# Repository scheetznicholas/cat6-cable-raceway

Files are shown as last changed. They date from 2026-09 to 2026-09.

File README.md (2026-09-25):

# Cat6 Cable Raceway (5-cable bundle, snap-on cover)

Printable wall raceway for a bundle of five Cat6 cables: straights, a flat 90° elbow, inside/outside
room-corner pieces and end caps.  Bambu H2S project files included.

| | |
|---|---|
| outer size | 32 wide × 20 tall |
| interior | 25.9 × 17.6 mm — 5 Cat6 stacked 3+2 with room, even 7 mm thick-jacket cable |
| cover | one-piece snap-over, 1.2 mm top and legs, 0.8 mm chamfered edges |
| base | 1.2 mm floor with lightening windows and 2 mm screw pads, 10 mm walls, countersunk #6 / M3.5 screw holes every 100 mm (or foam tape on the rails) |
| snap | 0.75 mm ridges on both parts with 20° hooked retention faces and 0.1 mm lateral preload: the sprung legs pull the cover tight to the wall, no rattle. 0.85 mm engagement, 0.70 % leg strain during snap-on, 0.20 % resting |
| filament | rev 2 (2026-09-24) uses ~36 % less than rev 1: 232 cm³ / ~290 g PLA per project, 38 cm³ per 300 mm of run |

## Files

- `CableRaceway_H2S_PLA.3mf` — Bambu PLA Basic, 0.20 mm, 3 walls, 15 % gyroid (all sections are solid walls anyway), no supports (2 plates)
- `CableRaceway_H2S_PETG.3mf` — same layout in Bambu PETG HF (tougher snap legs if the cover will come off a lot)
- `stl/` — every part, already in print orientation
- `generate_raceway.py` — build123d generator (all dimensions are parameters at the top)
- `check_mechanism.py` — solid-boolean fit checks: cover seats on the relaxed geometry without interference, the
  hooks retain it when lifted, the snap starts freely, the real geometry interferes only by the designed preload
  sliver at the ridges, a 21 × 14 mm cable bundle clears every piece, screw heads seat, end cap fits, leg strain,
  overhang audit of every STL (`check_mechanism.log` = last run, ALL PASS)
- `make_3mf.py` — builds the 3MF via the Bambu Studio CLI (`--petg` for the PETG version)

## What's in one project (per print of both plates)

| part | qty | what it is |
|---|---|---|
| straight_base_300 / straight_cover_300 | 4 + 4 | 1.2 m of run |
| straight_base_150 | 1 | half base so cover joints never sit over base joints |
| elbow_flat_base / elbow_flat_cover | 2 + 2 | 90° bend within the same wall (baseboard run turning up to a jack) |
| corner_inside_cover + corner_inside_base_stub | 1 + 2 | run goes around an inside (concave) room corner |
| corner_outside_cover + corner_outside_base_stub | 1 + 2 | run goes around an outside (convex) corner |
| end_cap | 2 | plugs an open end |

Need more run: duplicate plate 1 in Bambu Studio (or `Ctrl+D` the straights).  Don't need a corner type: delete it.

## Install

1. Start the base run with the 150 mm piece, then 300s.  Screw through the floor holes (#6 wood screws or
   drywall anchors) or use foam tape on the floor.  Butt base pieces end to end; the joints are hidden.
2. Flat elbow: the base is an L with a screw hole in each arm; the straight bases butt against its 55 mm arms
   and its 70 mm cover overlaps the joint.
3. Room corner: screw one stub to each wall with their mitred ends meeting at the corner, then the one-piece
   corner cover presses straight into the corner (both arms snap at once).  Straight base/cover continue from
   the stub ends.
4. Lay the cables in, then press each cover on: it has a lead-in ramp and clicks when seated.  The legs are
   sprung against the base and the ridges are hooked, so the cover is pulled tight to the wall and won't rattle
   or pop off.  To remove, slip a putty knife under a leg at the wall and lever the leg outward (about 1 mm)
   while lifting; work along the piece.
5. End caps push into the open interior at the run ends.

Cover joints on a long run: cut a straight cover shorter with a hacksaw if a joint would land on an elbow arm.

## Print notes

- Everything prints support-free in the exported orientation: bases floor-down, covers top-down, corner
  covers with one arm flat and the other standing.  The inside-corner cover stands on its leg edges, so it has
  a 5 mm per-object brim; the run under its flat arm is a 29.6 mm bridge (fine on an H2S).  The hooked retention
  faces are 0.8 mm ledges tilted 20°, the same two-line cantilever the rev 1 flat ledges were.
- Regenerate after changing parameters: `generate_raceway.py` → `check_mechanism.py` (must print ALL PASS) →
  `make_3mf.py`.
- If a printed cover feels too tight/loose, change `PRELOAD` (0.10; raise for tighter) or `VERT` (-0.05) in the
  generator and reprint one 150 mm base + cover to test; the other pieces inherit the same profile.  Rev 1
  (flat faces, 0.15/0.2 mm clearances, 1.6 mm sheets) printed fine but felt loose — that is why rev 2 preloads.
- Filament: set `FLOOR_WINDOWS = False` for a solid base floor (e.g. if you want full-width tape contact);
  it costs about 3.5 cm³ per 300 mm base.  Sheets are 1.2 mm = three 0.4 mm walls, so 2–3 wall loops print them solid.

## Wall-entry kit (run terminates into a stud bay)

Instead of ending a run with an `end_cap`, the run can dump its cables straight through the drywall into the
bay behind.  The plate *is* a piece of raceway: its front face carries the same outer profile and the same
absolute snap-ridge heights as a straight base, so stock covers and elbows mate to it flush.  Its floor is
2.4 mm instead of 1.2 (that floor is the visible face plate), and the floor simply stops over a
**25 × 44 mm hole** that drops into the wall.

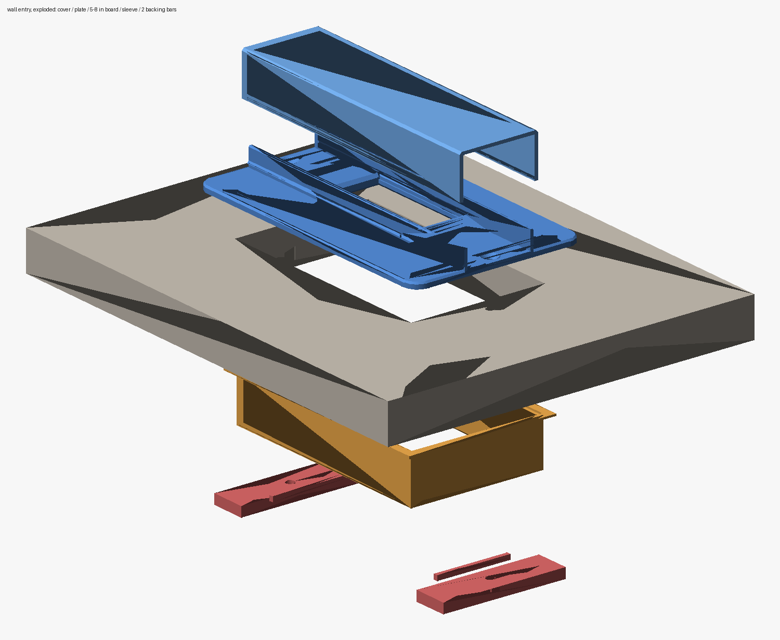
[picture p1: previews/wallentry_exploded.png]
exploded

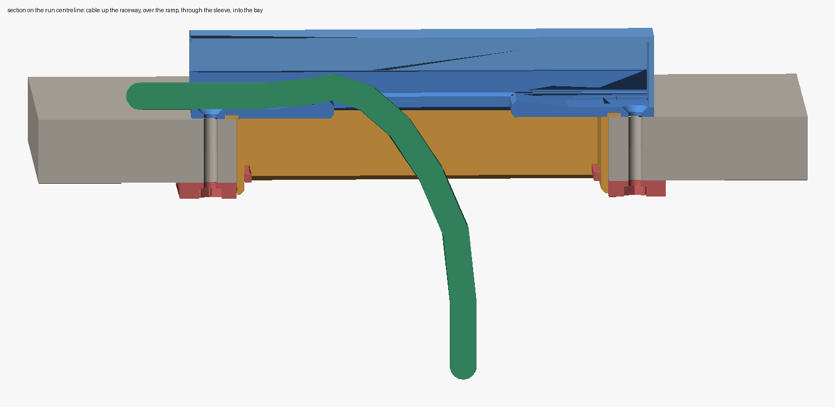
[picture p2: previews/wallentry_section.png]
section


| | |
|---|---|
| face plate | 69.85 × 114.3 mm — standard US single gang, 6 mm corner radius, 0.6 mm chamfer |
| wall cutout | 54.8 × 92.1 mm — Arlington LV1 low-voltage bracket size, so an off-the-shelf bracket or brush plate fits the same hole later |
| cable hole | 25 × 44 mm with 14 mm ramps each side (2 mm crest, 14.4 mm still clear under the cover).  44 mm is set by Cat6's 25 mm static bend radius (4 × OD) |
| sleeve | 60.2 × 97.5 mm lip, 19 mm deep — lines the cut so no cable ever touches cut gypsum.  The lip is **9.6 mm narrower and 16.8 mm shorter than the face plate** (4.83 mm hidden each side, 8.4 top and bottom) and nests in a 0.95 mm groove in the plate's back, so the plate still beds flat on the wall |
| fixing | two printed backing bars, no studs and no drywall anchors: each passes through the cutout, turns behind the board and clamps 691 mm² of intact gypsum (1382 mm² for the pair) |
| board | verified on both 1/2 in (12.7 mm) and 5/8 in (15.9 mm) |
| hardware | 2 × M3 × 30 countersunk + 2 × M3 nuts (nuts are captive in the bars).  On 5/8 in board the screw reaches 24.7 mm, leaving 5.3 mm spare |

### Files

- `WallEntry_H2S_PLA.3mf` / `WallEntry_H2S_PETG.3mf` — one plate, 6 objects: plate, cover, sleeve, 2 bars, template
- `generate_wallplate.py` — generator; imports `generate_raceway` and reuses its profile so the two can't drift
- `check_wallplate.py` — solid-boolean fit checks (`check_wallplate.log` = last run, ALL PASS)
- `render_wallentry.py` — the exploded and section previews above
- `make_3mf.py --wall` (add `--side` for a side-entry run, `--petg` for PETG) — builds the wall 3MF

### Parts

| part | qty | what it is |
|---|---|---|
| wallplate_entry_bottom | 1 | plate for a run arriving from below/above (along the plate's long axis) |
| wallplate_entry_side | - | same plate for a run arriving from the left/right — build with `--side` instead |
| wallplate_cover_bottom / _side | 1 | short cover with a **closed end**, trimmed to sit on the 2.4 mm floor |
| wall_sleeve | 1 | lines the cutout |
| wall_backing_bar | 2 | the clamp |
| wall_cut_template | 1 | 109.9 × 154.3 × 1.6 mm; trace the cutout and mark both screw holes |

The kit `end_cap` does **not** fit the plate — the plate's floor is 2.4 mm, so the cap would sit 1.2 mm proud
and its legs would foul.  Use `wallplate_cover_*`, whose far end is closed, as the end of the run.

### Install

1. Hold `wall_cut_template` on the wall where the run ends, level it, trace the 54.8 × 92.1 mm window and mark
   the two screw holes 52.5 mm above and below centre.  Check the bay is clear before cutting.
2. Cut the window (drywall saw) and drill the two 3.4 mm screw holes.
3. Thread an M3 × 30 countersunk screw through each plate hole and into the nut captive in a backing bar, a
   few turns only.  Feed each bar diagonally through the cutout, turn it flat behind the board and pull it
   back against the gypsum — the single rib on the bore side keys it against rotation, and the screw carries it.
4. Push the sleeve into the cutout from the front, lip against the wall face.
5. Set the plate over the sleeve (its back groove swallows the lip), then tighten both screws evenly until the
   bars bite.  Don't overtighten — you're clamping gypsum.
6. Bring the run in: the last base piece butts to the plate, cables lie over the ramps and drop through the
   hole into the bay.
7. Clip the closed-end cover on last; the hole and the screws disappear under it.

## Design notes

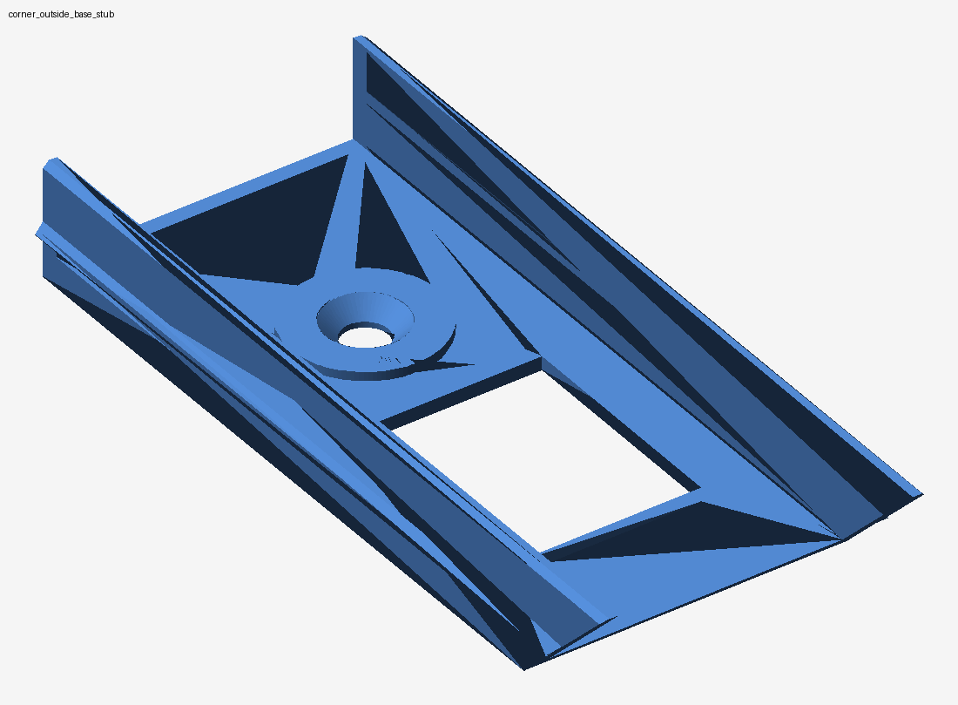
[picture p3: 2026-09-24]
previews/corner_outside_base_stub_iso.png

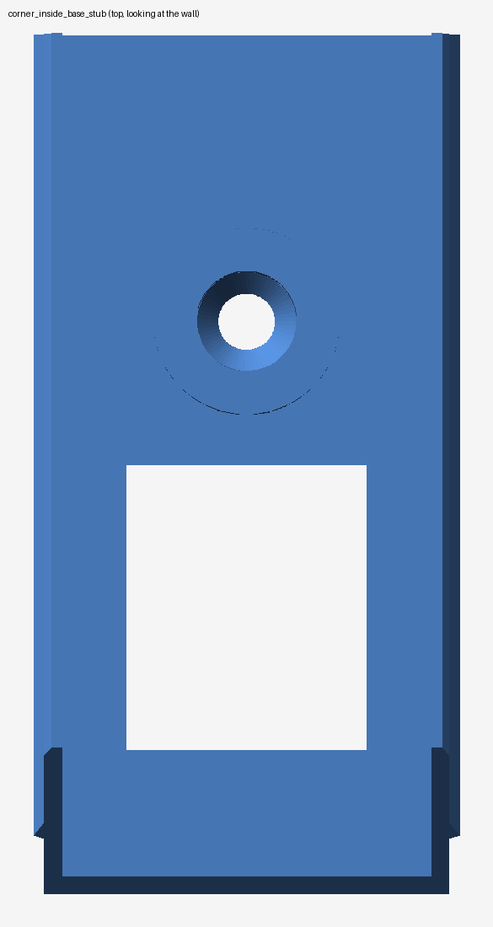
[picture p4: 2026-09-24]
previews/corner_inside_base_stub_top.png

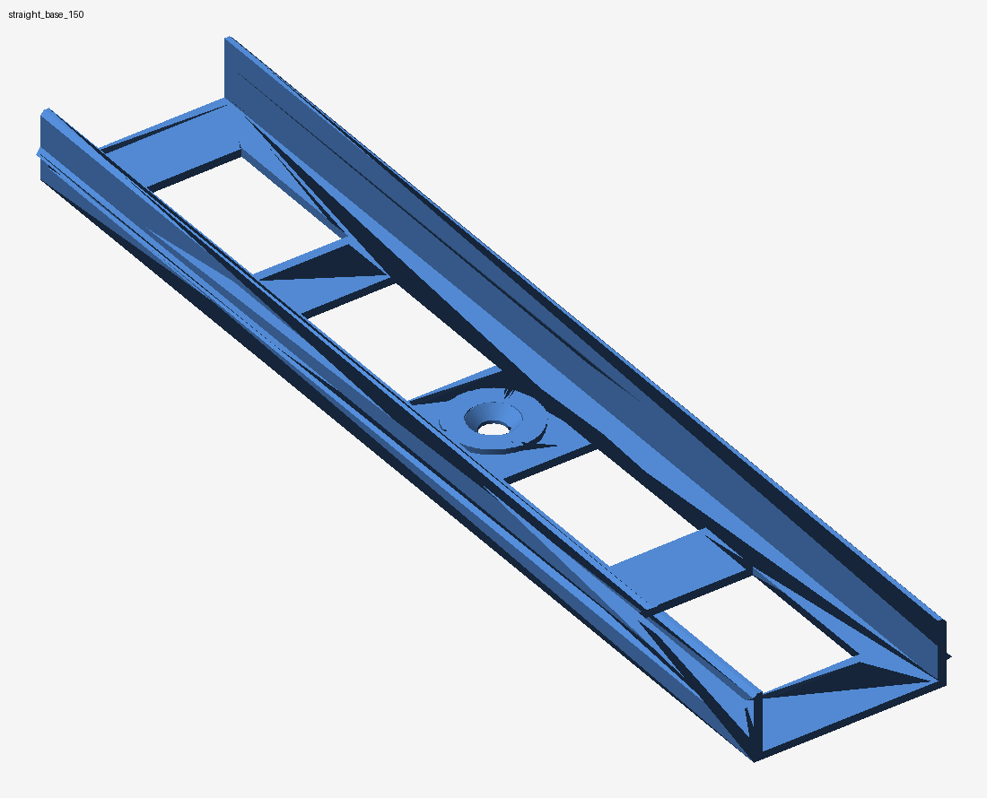
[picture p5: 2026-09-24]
previews/straight_base_150_iso.png

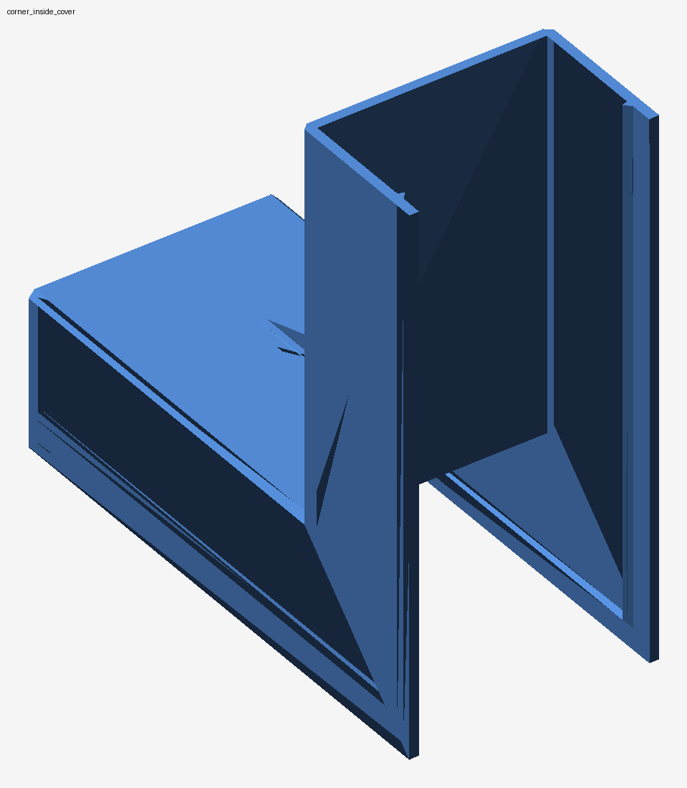
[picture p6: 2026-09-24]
previews/corner_inside_cover_iso.png

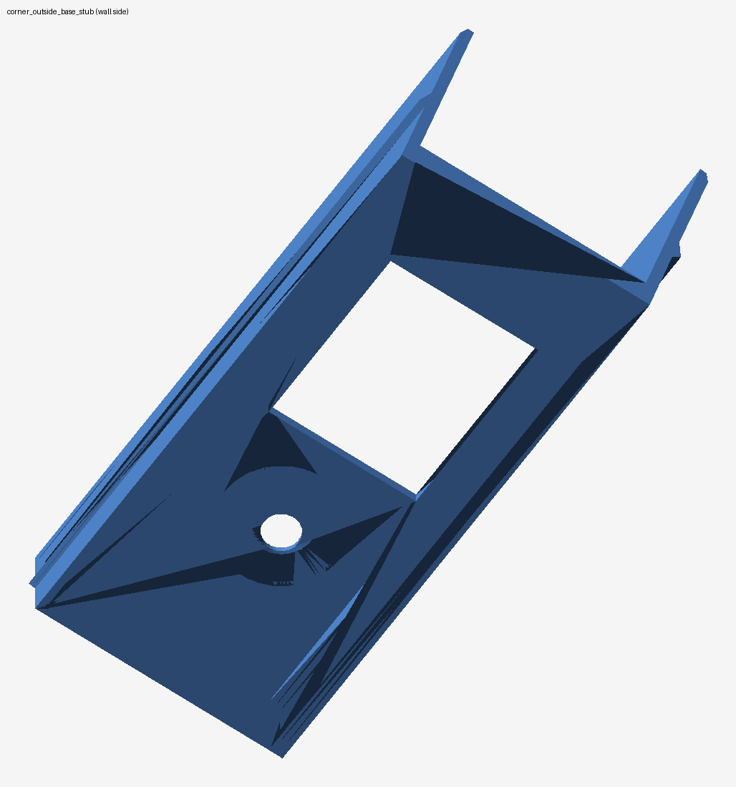
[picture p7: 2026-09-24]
previews/corner_outside_base_stub_under.png

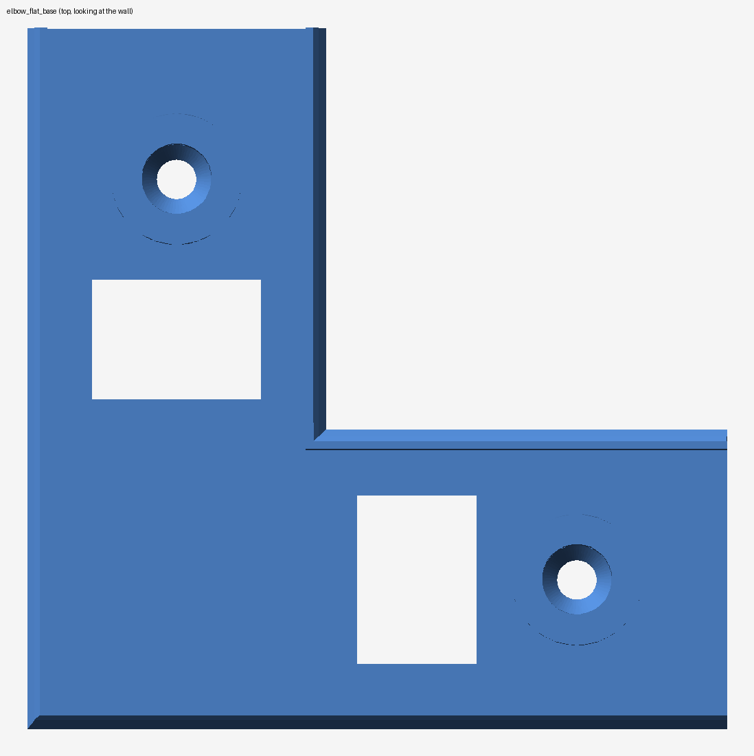
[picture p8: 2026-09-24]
previews/elbow_flat_base_top.png

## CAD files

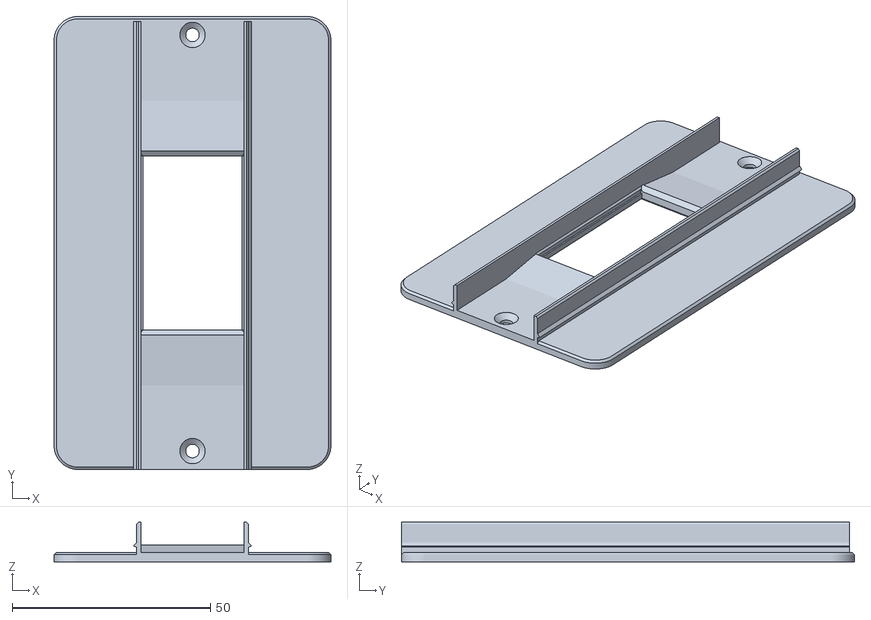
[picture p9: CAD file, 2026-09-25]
stl/wallplate_entry_bottom.stl
69.8 x 114.3 x 10.0

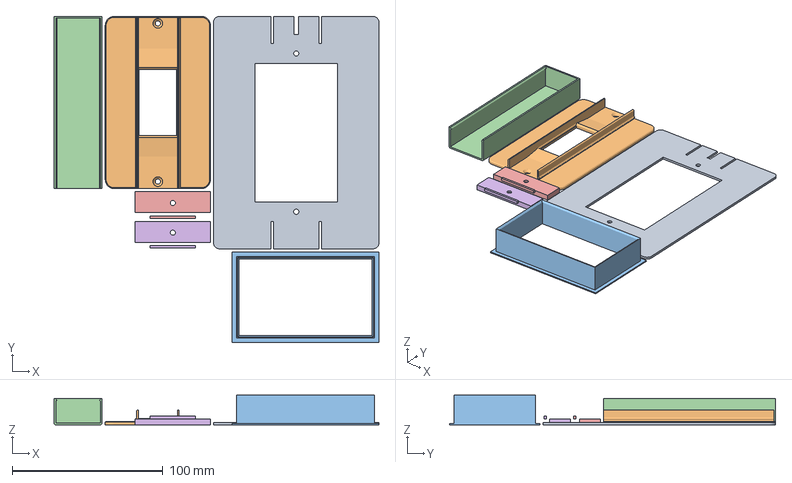
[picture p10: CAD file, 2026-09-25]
WallEntry_H2S_PLA.3mf
215.7 x 216.5 x 19.8 mm
wall_cut_template.stl
wallplate_entry_bottom.stl
wall_sleeve.stl
wallplate_cover_bottom.stl
wall_backing_bar_1.stl
wall_backing_bar_2.stl

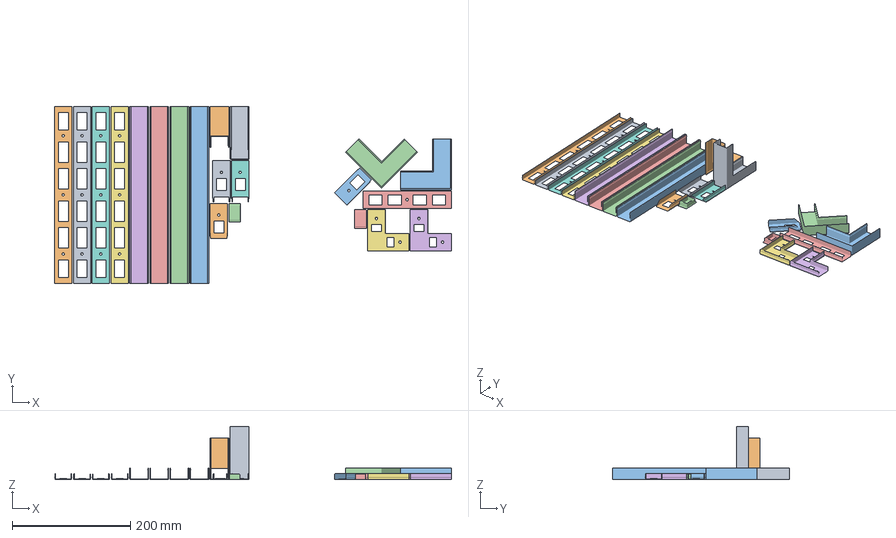
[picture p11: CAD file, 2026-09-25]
CableRaceway_H2S_PLA.3mf
671.7 x 300.0 x 90.0 mm
corner_outside_cover.stl
corner_inside_cover.stl
straight_cover_300_1.stl
straight_cover_300_2.stl
straight_cover_300_3.stl
straight_cover_300_4.stl
straight_base_300_1.stl
straight_base_300_2.stl
straight_base_300_3.stl
straight_base_300_4.stl
elbow_flat_cover_1.stl
elbow_flat_cover_2.stl
straight_base_150.stl
elbow_flat_base_1.stl
elbow_flat_base_2.stl
corner_outside_base_stub_1.stl
corner_outside_base_stub_2.stl
corner_inside_base_stub_1.stl
corner_inside_base_stub_2.stl
end_cap_1.stl
end_cap_2.stl

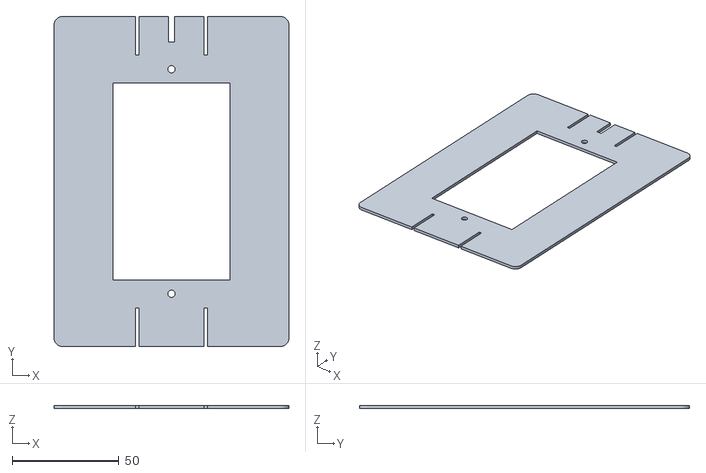
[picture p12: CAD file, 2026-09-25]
stl/wall_cut_template.stl
109.8 x 154.3 x 1.60

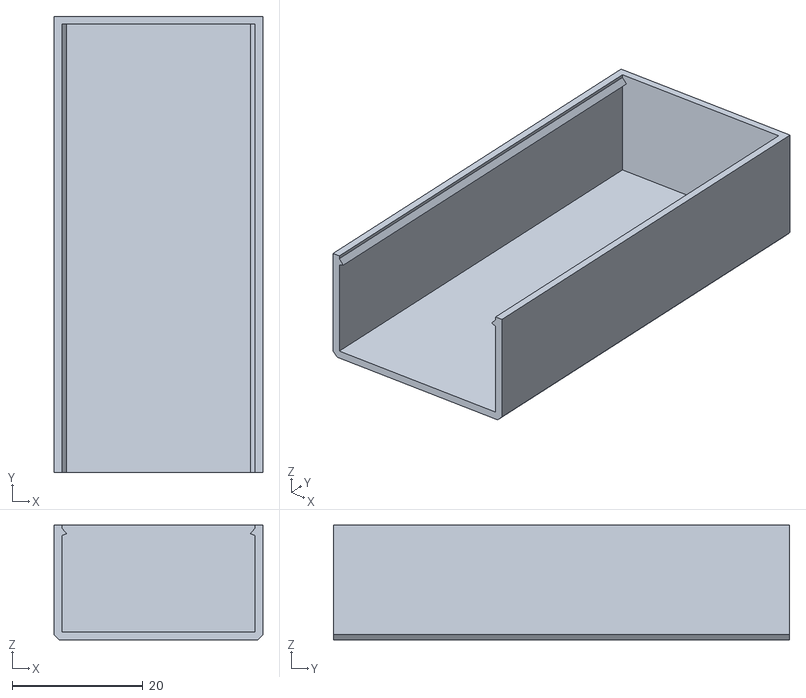
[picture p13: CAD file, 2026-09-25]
stl/wallplate_cover_side.stl
32.0 x 69.8 x 17.6

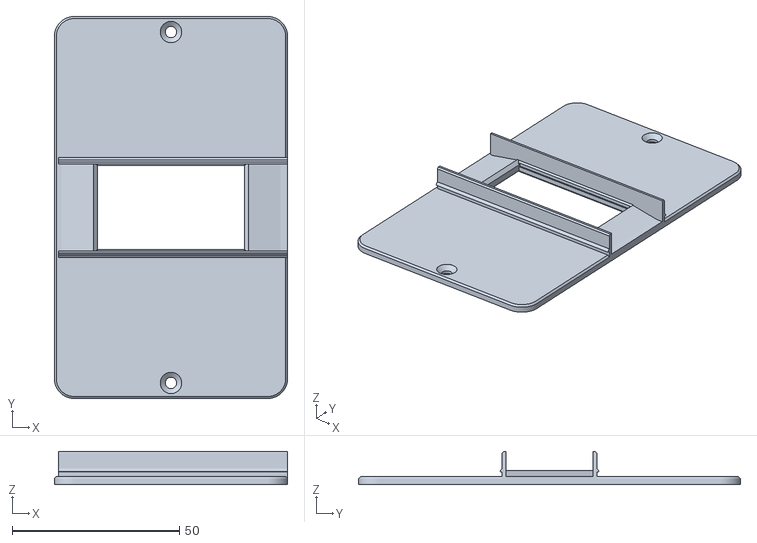
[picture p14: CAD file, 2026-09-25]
stl/wallplate_entry_side.stl
69.8 x 114.3 x 10.0

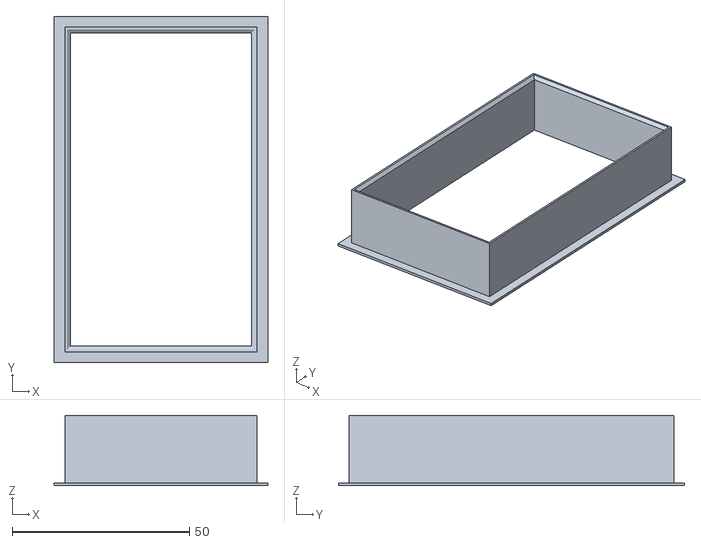
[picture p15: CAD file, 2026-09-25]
stl/wall_sleeve.stl
60.2 x 97.5 x 19.8

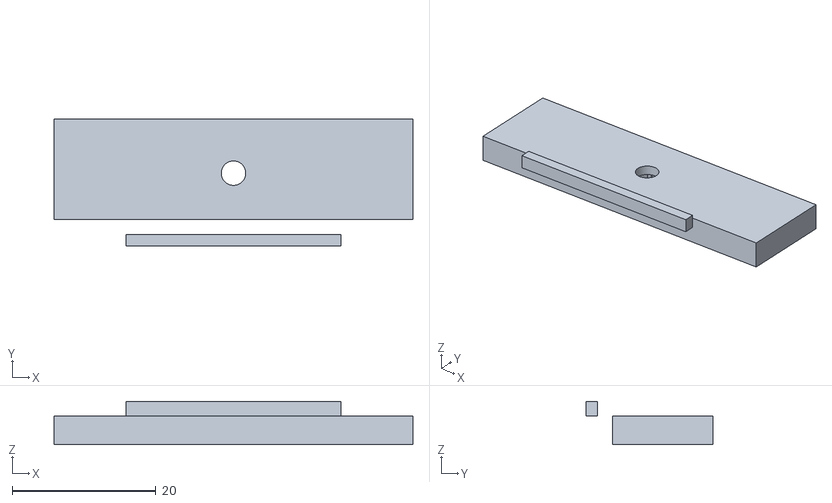
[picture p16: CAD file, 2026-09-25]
stl/wall_backing_bar.stl
50.0 x 17.7 x 6.00

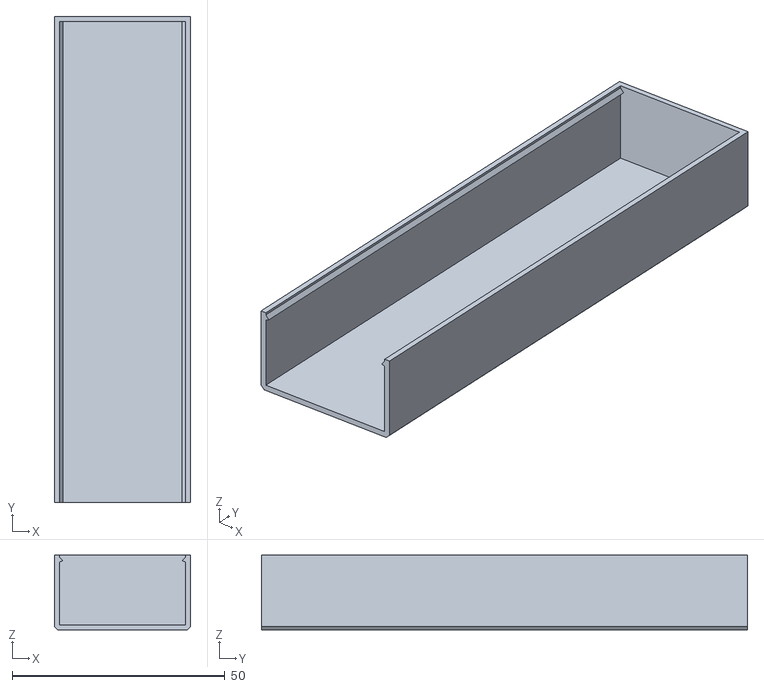
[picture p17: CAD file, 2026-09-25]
stl/wallplate_cover_bottom.stl
32.0 x 114.3 x 17.6

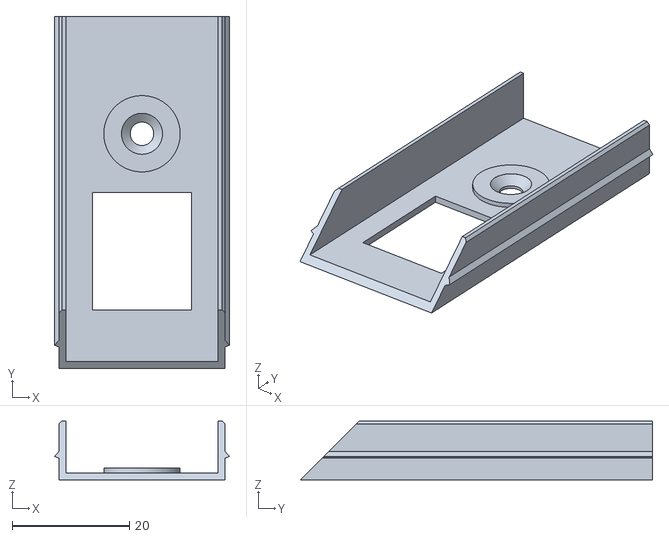
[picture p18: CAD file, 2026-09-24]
stl/corner_inside_base_stub.stl
29.8 x 60.0 x 10.00

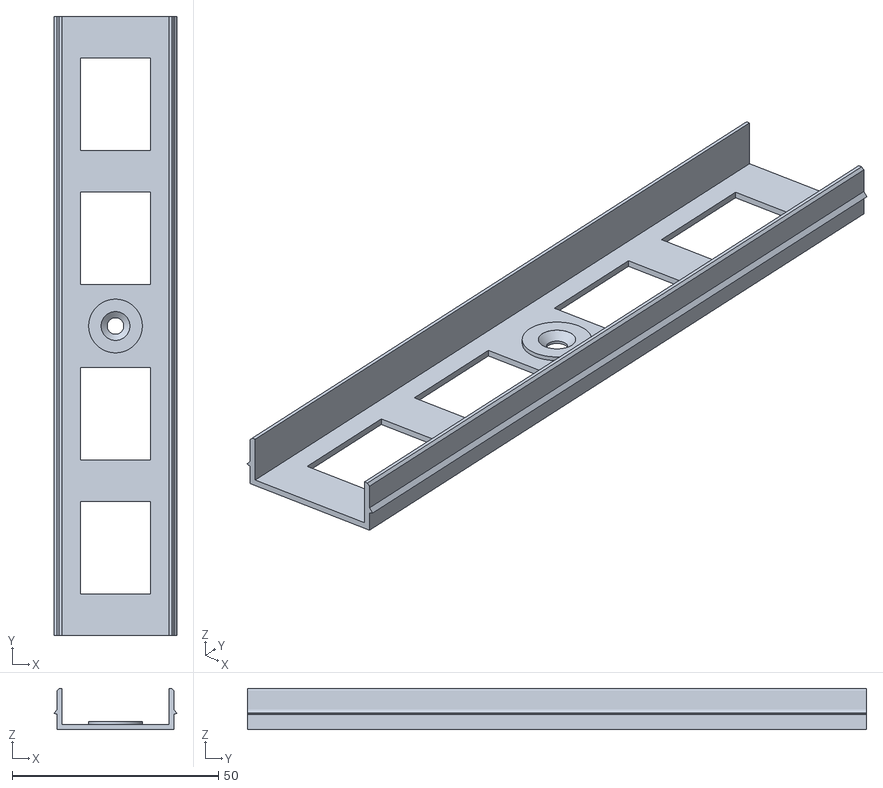
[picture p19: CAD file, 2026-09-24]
stl/straight_base_150.stl
29.8 x 150.0 x 10.0

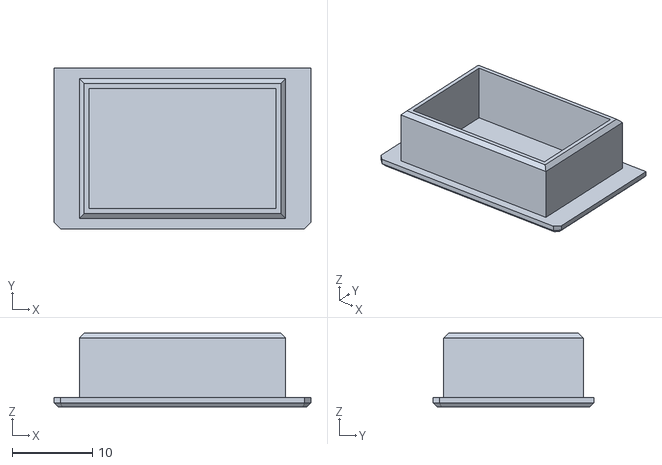
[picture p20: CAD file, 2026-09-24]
stl/end_cap.stl
32.0 x 20.0 x 9.20

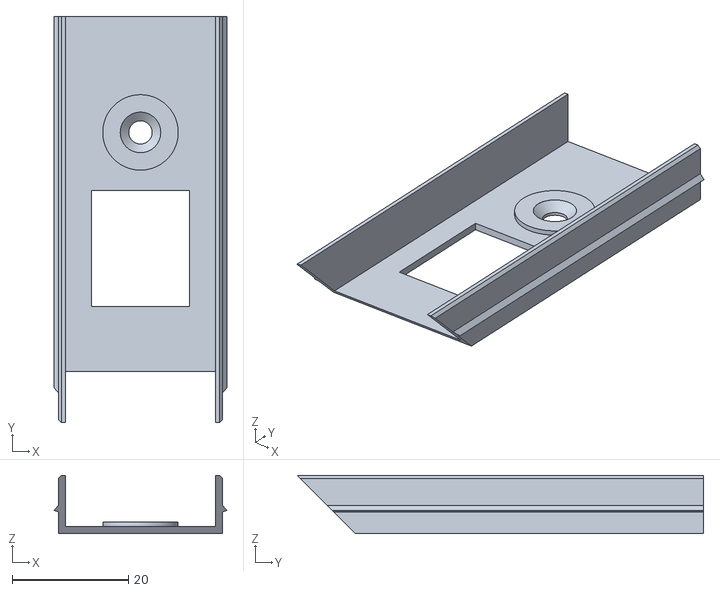
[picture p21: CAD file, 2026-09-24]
stl/corner_outside_base_stub.stl
29.8 x 70.0 x 10.0

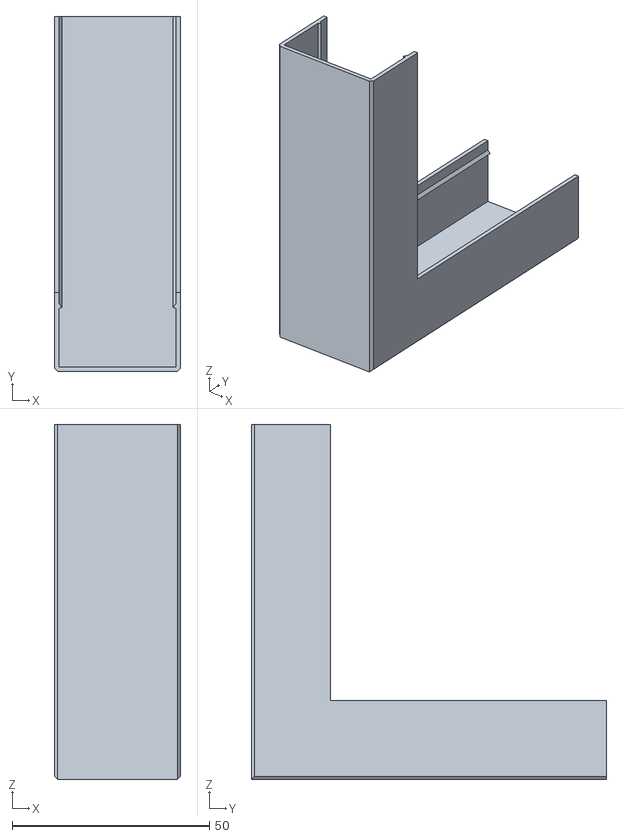
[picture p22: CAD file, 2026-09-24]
stl/corner_outside_cover.stl
32.0 x 90.0 x 90.0

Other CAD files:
WallEntry_H2S_PETG.3mf
CableRaceway_H2S_PETG.3mf
stl/straight_cover_300.stl
stl/elbow_flat_base.stl
stl/corner_inside_cover.stl
stl/elbow_flat_cover.stl
stl/straight_base_300.stl

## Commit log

2026-09-24 Cat6 5-cable snap-on wall raceway: build123d generator, fit checks, H2S PLA/PETG 3MFs
    Claude-Session: https://claude.ai/code/session_01N21NqbP23F8Y1zRpfwzhw1
    [CableRaceway_H2S_PETG.3mf, CableRaceway_H2S_PLA.3mf, corner_inside_base_stub.stl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]
2026-09-24 Rev 2: preloaded hooked snap (fixes loose cover) and ~36% less filament
    - snap: 20 deg hooked retention faces + 0.10 mm lateral preload (+0.05 vertical
    interference) replace the flat faces and 0.15/0.2 mm clearances that let the
    rev 1 cover rattle; ramps eased to ~48 deg; resting strain 0.20%, snap-on 0.70%
    - material: 1.2 mm cover top/legs and base floor/walls (were 1.6/2.0), 10 mm
    base walls (were 12), windowed base floor with 2 mm screw pads, hollow end-cap
    plug -> 232 cm3 per project (was 359), 38 cm3 per 300 mm of run (was 59)
    - generator gains derive() so the checks can run on the relaxed geometry; new
    real-geometry preload-sliver check, screw-head seat check, floor-end check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
    [CableRaceway_H2S_PETG.3mf, CableRaceway_H2S_PLA.3mf, corner_inside_base_stub.stl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]
2026-09-25 Add wall-entry kit: face plate, sleeve, backing bars, cut template
    Lets a run terminate by dropping its cables straight through the drywall
    into the stud bay instead of ending in an end cap.
    - generate_wallplate.py: imports generate_raceway and reuses its profile,
    so the plate carries the same outer shape and the same absolute snap
    ridge heights as a straight base (stock covers and elbows mate flush).
    Floor thickened 1.2 -> 2.4 mm; that floor is the visible face plate.
    - 69.85 x 114.3 mm single-gang plate over a 54.8 x 92.1 mm Arlington LV1
    cutout, so an off-the-shelf LV bracket or brush plate fits the same
    hole later.
    - 25 x 44 mm cable hole with 14 mm ramps; 44 mm is Cat6's 25 m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
    [CableRaceway_H2S_PLA.3mf, WallEntry_H2S_PETG.3mf, WallEntry_H2S_PLA.3mf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]
